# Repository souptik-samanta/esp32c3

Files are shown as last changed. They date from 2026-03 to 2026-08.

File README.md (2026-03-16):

# ESP32-C3 Custom Development Board

A compact, custom-designed ESP32-C3 development board with USB-C connectivity, onboard antenna, and a clean PCB layout.

---

## 3D Render



The board features a USB-C connector on the left side, two tactile switches (BOOT and EN), the ESP32-C3 QFN package at the center-right, a PCB trace antenna on the far right, and a 4-pin UART header (3V3, RXD, TXD, GND) along the bottom edge. All passives are 0402/0603 for a tight layout.
with onboard temp humidity barometer and pressure
---

## PCB Layout

### 3d Render

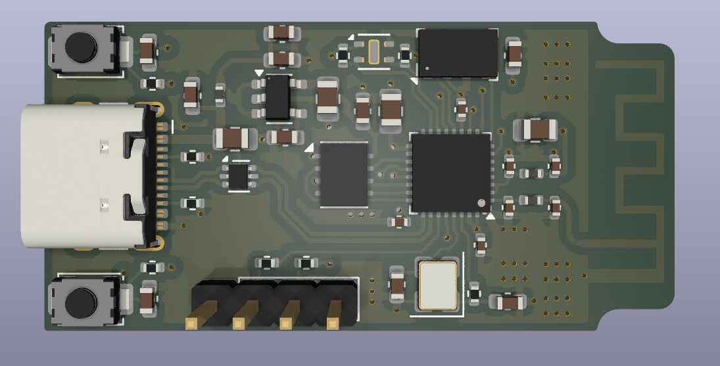
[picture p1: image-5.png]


### Front Copper

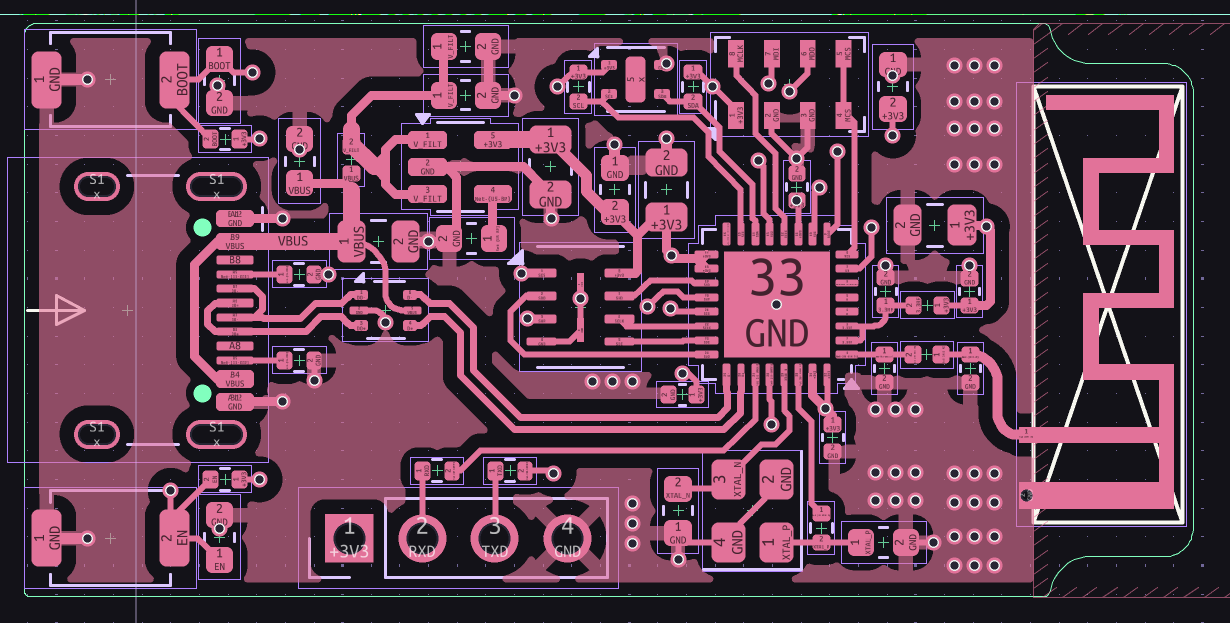
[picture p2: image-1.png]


### Back Copper

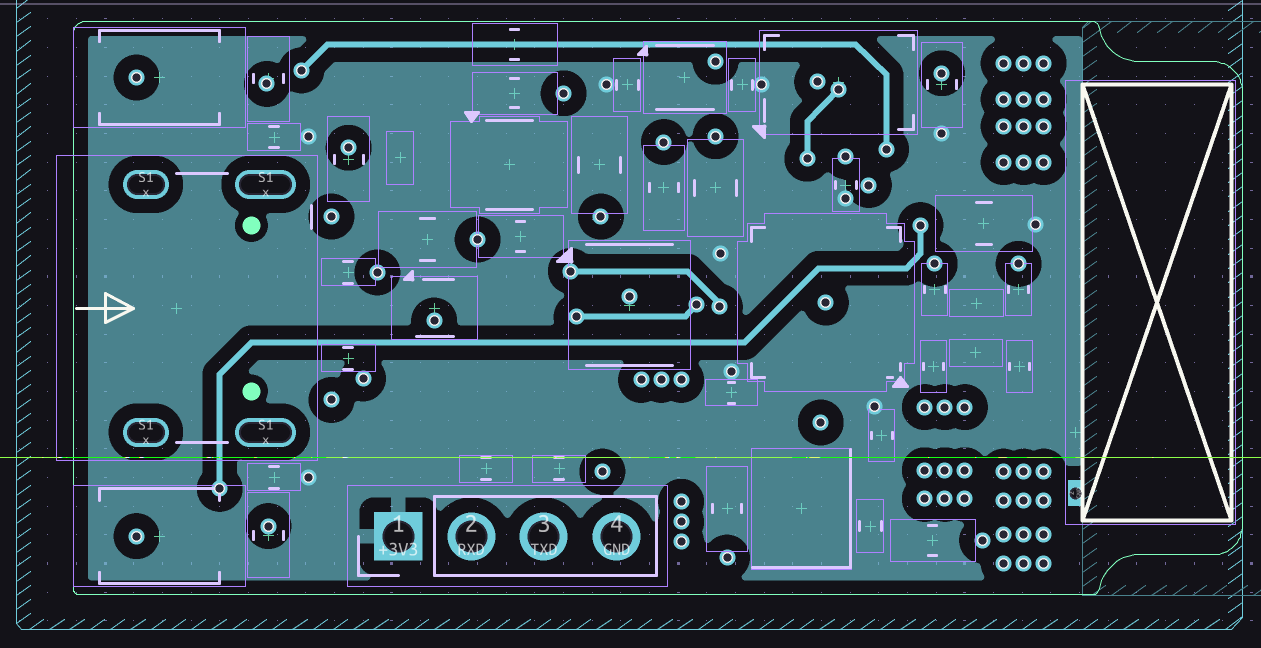
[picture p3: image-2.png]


### IN 1

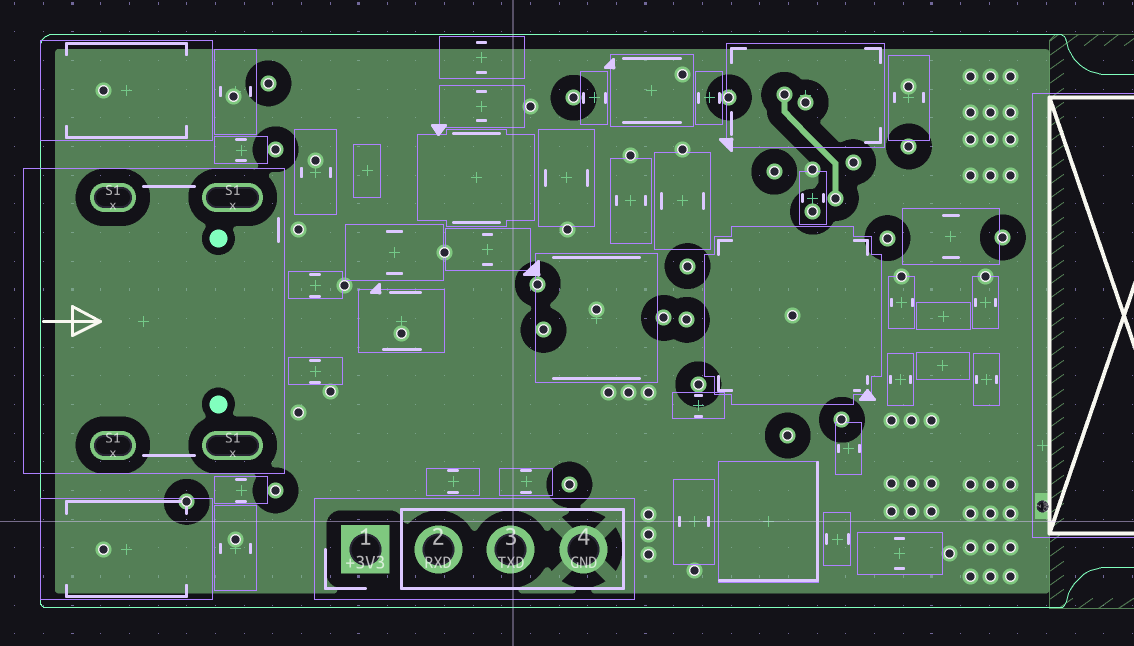
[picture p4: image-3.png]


### IN 2

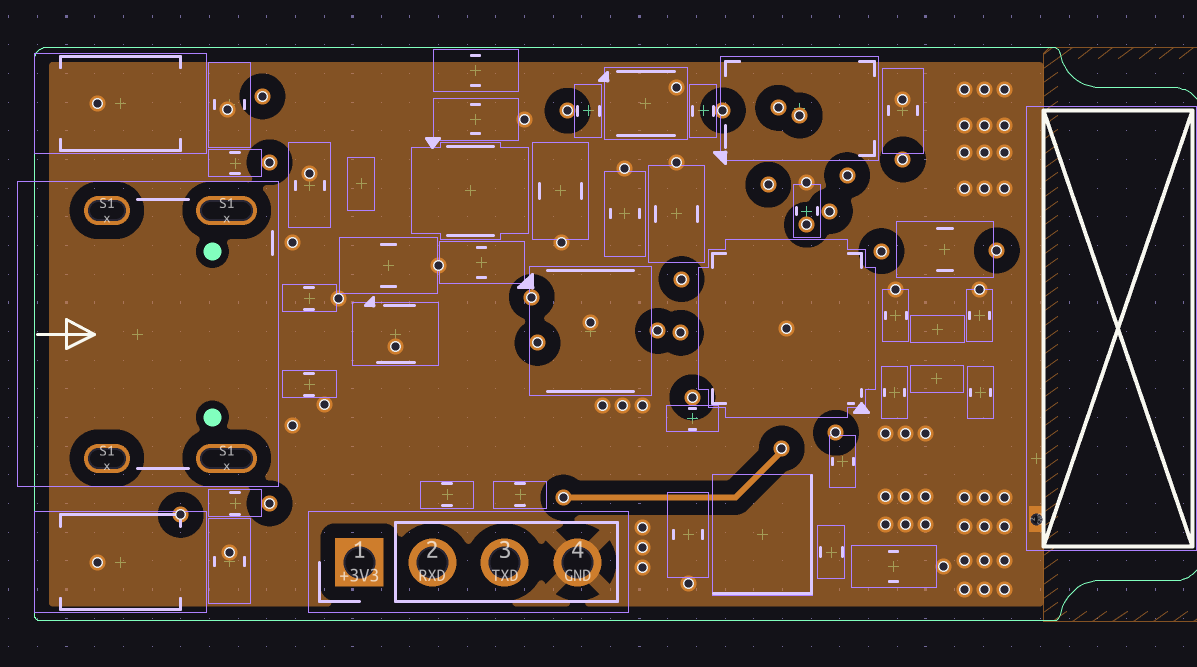
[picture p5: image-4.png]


### Board Outline

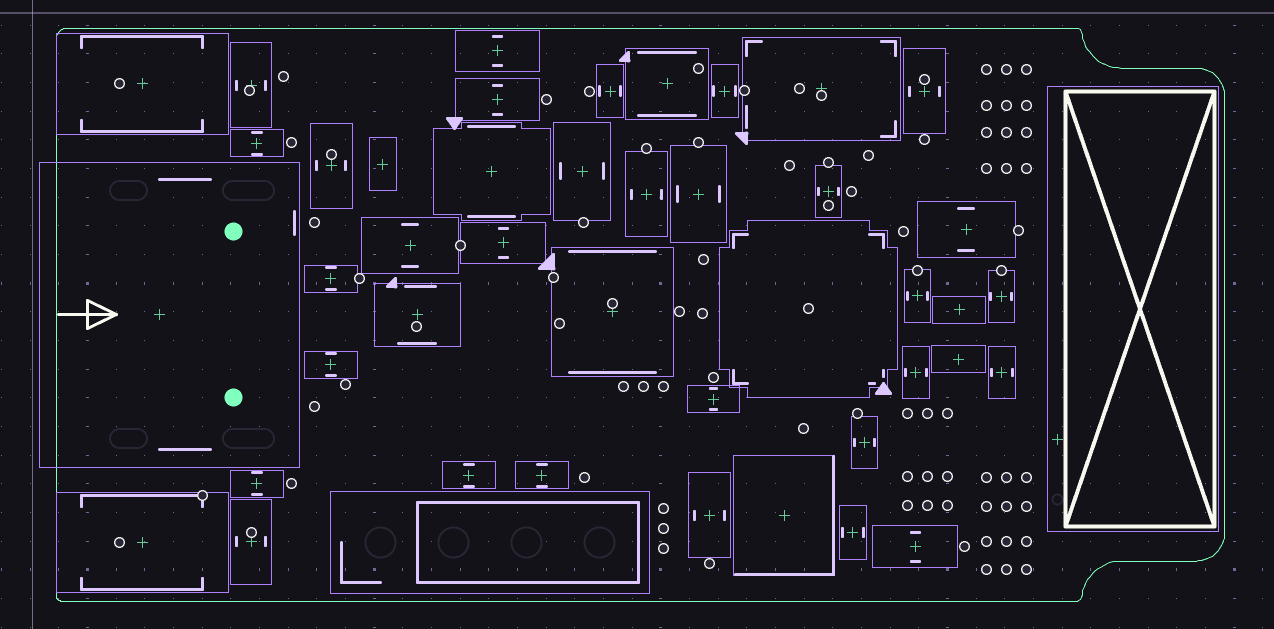
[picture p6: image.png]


---

## Features

- **Microcontroller:** ESP32-C3 (RISC-V single-core, up to 160 MHz)
- **Wireless:** 2.4 GHz Wi-Fi 4 and Bluetooth 5 (LE)
- **USB-C:** For power and programming, no external UART adapter needed
- **PCB Antenna:** Integrated trace antenna, no external module required
- **UART Header:** 4-pin breakout (3V3, RXD, TXD, GND) for serial debugging
- **Buttons:** BOOT and EN (reset) tactile switches
- **Power:** USB 5V input with onboard 3.3V regulation
- **Form Factor:** Compact two-layer board, hand-solderable with hot air

---

## Pin Header

| Pin | Function |
|-----|---|
| 1 | +3V3 |
| 2 | RXD |
| 3 | TXD |
| 4 | GND |

---

## Getting Started

1. Connect the board via USB-C to your computer.
2. Install the [ESP-IDF](https://docs.espressif.com/projects/esp-idf/en/latest/esp32c3/get-started/) toolchain or use the Arduino core for ESP32.
3. Hold the BOOT button while pressing EN to enter download mode.
4. Flash your firmware and hit EN to run.

For serial debugging without USB, wire up the 4-pin UART header to any USB-to-serial adapter at 3.3V logic levels.

## License

Hardware design files are provided as-is. Use at your own risk. Feel free to fork, modify, and build on this design for personal or commercial projects.

To make this 
Please download the esp32.zip(gerber files)
go to jlcpcb upload
upload the BOM AND cpl files and order!!
that simple

# Bill of Materials (BOM)

| Comment | Designator | Footprint | JLCPCB Part # |
|---|---|---|---|
| W25Q128JVP | U2 | Winbond_USON-8-2EP_3x4mm_P0.8mm_EP0.2x0.8mm | C2999380 |
| RESET | SW2, SW1 | SW_SPST_TS-1088-xR020 | C778164 |
| 27pF | C1, C2 | 0603 | C1656 |
| 470Ω | R3, R4 | 0402 | C25117 |
| USBLC6-2P6 | U3 | SOT-666 | C15999 |
| 10µF | C14, C15, C3, C7 | 0805 | C440198 |
| 100nF | C4, C5, C6, C8, C9 | 0402 | C1525 |
| 5.1KΩ | R2, R5, R6, R7, R8, R9 | 0402 | C25905 |
| ESP32-C3 | U1 | QFN-32-1EP_5x5mm_P0.5mm_EP3.7x3.7mm | C2838500 |
| 22Ω | R1 | 0402 | C25092 |
| 100nF | C10, C11, C12, C13, C16, C18, C19 | 0603 | C14663 |
| USB_C_Receptacle_USB2.0_14P | J1 | USB_C_Receptacle_HCTL_HC-TYPE-C-16P-01A | C2997432 |
| MS5611-01BA | U4 | LGA-8_3x5mm_P1.25mm | C15639 |
| 2.2µF | C17 | 0603 | C23630 |
| 2.2nH | L1, L2, L3 | 0402 | C6652831 |
| SPX3819M5-L-3-3 | U5 | SOT-23-5 | C20617301 |
| 3.3pF | C20, C21 | 0402 | C1565 |
| Crystal_GND24 | Y2 | Crystal_SMD_3225-4Pin_3.2x2.5mm | C5444549 |
| SHTC3 | U6 | Sensirion_DFN-4-1EP_2x2mm_P1mm_EP0.7x1.6mm | C2880044 |

---

## Cost Breakdown

- PCB Fabrication Cost: **$10 USD**
- Total Cost (Including Shipping): **$~ 162 USD**

# How to use it / assemble it
Go to jlcpcb upload gerber select pcba 
give the cpl and desgnator files
order it
wait 
and there u have it 
connect usb c cable use arduino ide thonny esp32 tool whatever u want lol
---

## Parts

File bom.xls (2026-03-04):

Comment | Designator | Footprint | JLCPCB Part #
W25Q128JVP | U2 | Winbond_USON-8-2EP_3x4mm_P0.8mm_EP0.2x0.8mm | C2999380
RESET | SW2,SW1,SW2,SW1 | SW_SPST_TS-1088-xR020 | C778164
27pF | C1,C2 | 0603 | C1656
470 | R3,R4 | 0402 | C25117
USBLC6-2P6 | U3 | SOT-666 | C15999
10u | C14,C15,C3,C7 | 0805 | C440198
100n | C4,C5,C6,C8,C9 | 0402 | C1525
5.1K | R2,R5,R6,R7,R8,R9 | 0402 | C25905
ESP32-C3 | U1 | QFN-32-1EP_5x5mm_P0.5mm_EP3.7x3.7mm | C2838500
22 | R1 | 0402 | C25092
100n | C10,C11,C12,C13,C16,C18,C19 | 0603 | C14663
USB_C_Receptacle_USB2.0_14P | J1 | USB_C_Receptacle_HCTL_HC-TYPE-C-16P-01A | C2997432
MS5611-01BA | U4 | LGA-8_3x5mm_P1.25mm | C15639
2.2u | C17 | 0603 | C23630
2.2nH | L1,L2,L3 | 0402 | C6652831
SPX3819M5-L-3-3 | U5 | SOT-23-5 | C20617301
3.3pF | C20,C21 | 0402 | C1565
Crystal_GND24 | Y2 | Crystal_SMD_3225-4Pin_3.2x2.5mm | C5444549
SHTC3 | U6 | Sensirion_DFN-4-1EP_2x2mm_P1mm_EP0.7x1.6mm | C2880044

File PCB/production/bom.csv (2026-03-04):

Designator | Footprint | Quantity | Value | LCSC Part #
AE1 | Texas_SWRA117D_2.4GHz_Left | 1 | Antenna_Shield
C1, C2 | 0603 | 2 | 27pF
C10, C11, C12, C13, C16, C18, C19 | 0603 | 7 | 100n
C14, C15, C3, C7 | 0805 | 4 | 10u
C17 | 0603 | 1 | 2.2u
C20, C21 | 0402 | 2 | 3.3pF
C4, C5, C6, C8, C9 | 0402 | 5 | 100n
J1 | USB_C_Receptacle_HCTL_HC-TYPE-C-16P-01A | 1 | USB_C_Receptacle_USB2.0_14P
J2 | PinHeader_1x04_P2.54mm_Vertical | 1 | Conn_01x04_Pin
L1, L2, L3 | 0402 | 3 | 2.2nH
R1 | 0402 | 1 | 22
R2, R5, R6, R7, R8, R9 | 0402 | 6 | 5.1K
R3, R4 | 0402 | 2 | 470
SW1 | SW_SPST_TS-1088-xR020 | 1 | RESET
SW2 | SW_SPST_TS-1088-xR020 | 1 | BOOT
U1 | QFN-32-1EP_5x5mm_P0.5mm_EP3.7x3.7mm | 1 | ESP32-C3
U2 | Winbond_USON-8-2EP_3x4mm_P0.8mm_EP0.2x0.8mm | 1 | W25Q128JVP
U3 | SOT-666 | 1 | USBLC6-2P6
U4 | LGA-8_3x5mm_P1.25mm | 1 | MS5611-01BA
U5 | SOT-23-5 | 1 | SPX3819M5-L-3-3
U6 | Sensirion_DFN-4-1EP_2x2mm_P1mm_EP0.7x1.6mm | 1 | SHTC3
Y2 | Crystal_SMD_3225-4Pin_3.2x2.5mm | 1 | Crystal_GND24

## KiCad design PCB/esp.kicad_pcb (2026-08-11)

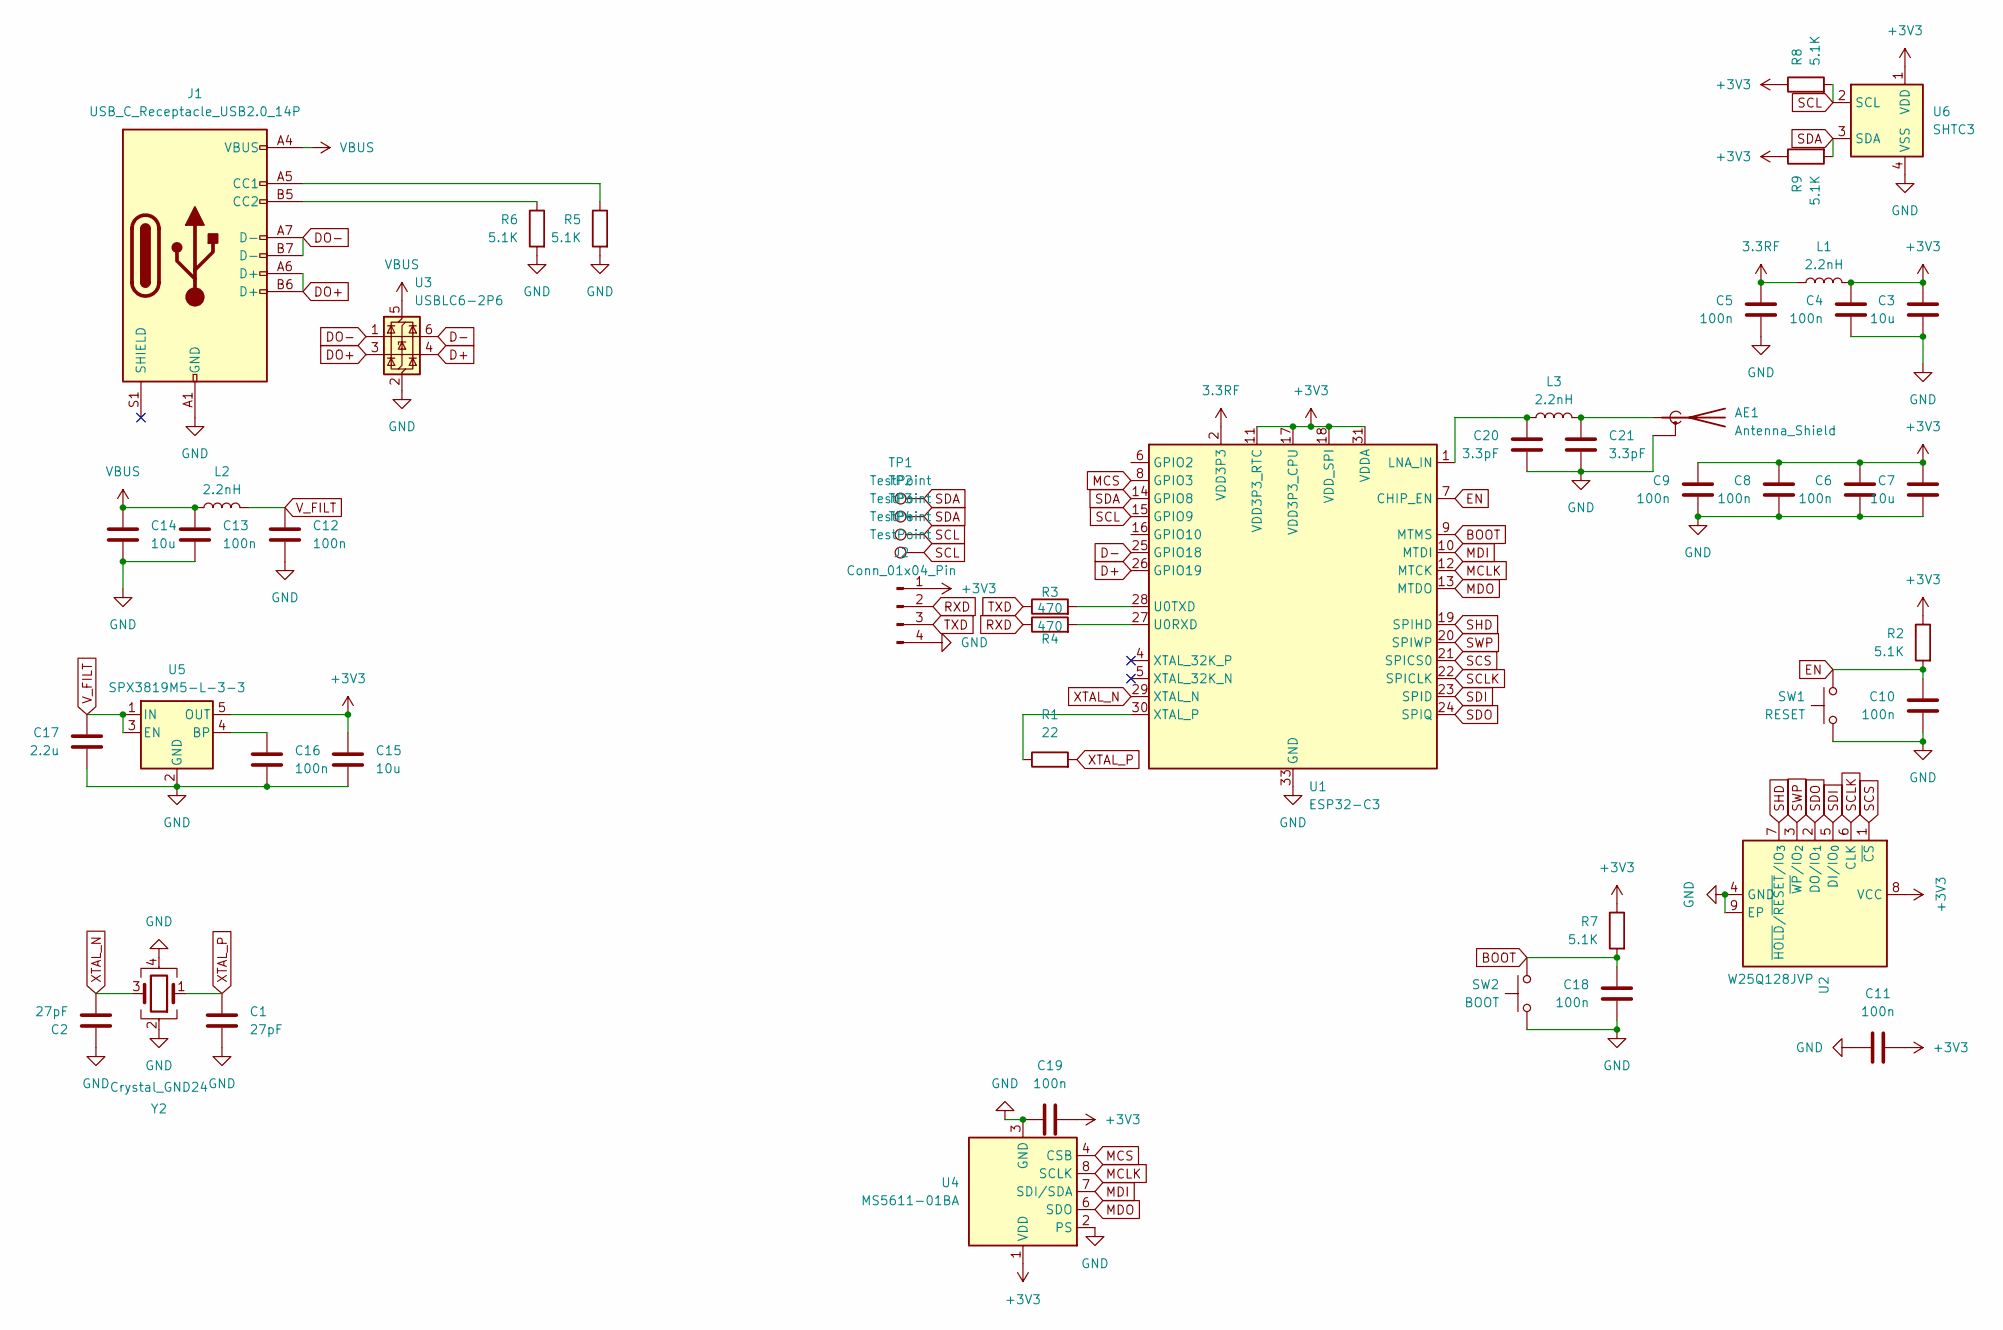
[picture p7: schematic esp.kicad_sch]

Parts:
AE1: Antenna_Shield; Texas_SWRA117D_2.4GHz_Left
C1, C2: 27pF; C_0603_1608Metric
C3, C7, C14, C15: 10u; C_0805_2012Metric
C4, C5, C6, C8, C9: 100n; C_0402_1005Metric
C10, C11, C12, C13, C16, C18, C19: 100n; C_0603_1608Metric
C17: 2.2u; C_0603_1608Metric
C20, C21: 3.3pF; C_0402_1005Metric
J1: USB_C_Receptacle_USB2.0_14P; USB_C_Receptacle_HCTL_HC-TYPE-C-16P-01A
J2: Conn_01x04_Pin; PinHeader_1x04_P2.54mm_Vertical
L1, L2, L3: 2.2nH; L_0402_1005Metric
R1: 22; R_0402_1005Metric
R2, R5, R6, R7, R8, R9: 5.1K; R_0402_1005Metric
R3, R4: 470; R_0402_1005Metric
SW1: RESET; SW_SPST_TS-1088-xR020
SW2: BOOT; SW_SPST_TS-1088-xR020
TP1, TP2, TP3, TP4: TestPoint; PinHeader_1x01_P1.00mm_Vertical
U1: ESP32-C3; QFN-32-1EP_5x5mm_P0.5mm_EP3.7x3.7mm
U2: W25Q128JVP; Winbond_USON-8-2EP_3x4mm_P0.8mm_EP0.2x0.8mm
U3: USBLC6-2P6; SOT-666
U4: MS5611-01BA; LGA-8_3x5mm_P1.25mm
U5: SPX3819M5-L-3-3; SOT-23-5
U6: SHTC3; Sensirion_DFN-4-1EP_2x2mm_P1mm_EP0.7x1.6mm
Y2: Crystal_GND24; Crystal_SMD_3225-4Pin_3.2x2.5mm

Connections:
3.3RF: C5.1, L1.2, U1.2 (VDD3P3), U1.3 (VDD3P3)
+3V3: C3.1, C4.1, C6.1, C7.1, C8.1, C9.1, C11.2, C15.1, C19.2, J2.1, L1.1, R2.1, R7.1, R8.1, R9.1, U1.11 (VDD3P3_RTC), U1.17 (VDD3P3_CPU), U1.18 (VDD_SPI), U1.31 (VDDA), U1.32 (VDDA), U2.8 (VCC), U4.1 (VDD), U5.5 (OUT), U6.1 (VDD)
BOOT: C18.1, R7.2, SW2.2, U1.9 (MTMS)
D+: U1.26 (GPIO19), U3.4 (I/O2)
D-: U1.25 (GPIO18), U3.6 (I/O1)
DO+: J1.A6 (D+), J1.B6 (D+), U3.3 (I/O2)
DO-: J1.A7 (D-), J1.B7 (D-), U3.1 (I/O1)
EN: C10.1, R2.2, SW1.2, U1.7 (CHIP_EN)
GND: AE1.2 (Shield), C1.2, C2.1, C3.2, C4.2, C5.2, C6.2, C7.2, C8.2, C9.2, C10.2, C11.1, C12.2, C13.2, C14.2, C15.2, C16.2, C17.2, C18.2, C19.1, C20.2, C21.2, J1.A1 (GND), J1.A12 (GND), J1.B1 (GND), J1.B12 (GND), J2.4, R5.2, R6.2, SW1.1, SW2.1, U1.33 (GND), U2.4 (GND), U2.9 (EP), U3.2 (GND), U4.2 (PS), U4.3 (GND), U5.2 (GND), U6.4 (VSS), Y2.2, Y2.4
MCLK: U1.12 (MTCK), U4.8 (SCLK)
MCS: U1.8 (GPIO3), U4.4 (CSB), U4.5 (CSB)
MDI: U1.10 (MTDI), U4.7 (SDI/SDA)
MDO: U1.13 (MTDO), U4.6 (SDO)
unnamed: AE1.1 (A), C21.1, L3.1
unnamed: J1.A5 (CC1), R5.1
unnamed: J1.B5 (CC2), R6.1
unnamed: C20.1, L3.2, U1.1 (LNA_IN)
unnamed: R4.2, U1.27 (U0RXD)
unnamed: R3.2, U1.28 (U0TXD)
unnamed: R1.1, U1.30 (XTAL_P)
unnamed: C16.1, U5.4 (BP)
RXD: J2.2, R4.1
SCL: R8.2, TP3.1, TP4.1, U1.15 (GPIO9), U6.2 (SCL)
SCLK: U1.22 (SPICLK), U2.6 (CLK)
SCS: U1.21 (SPICS0), U2.1 (~CS)
SDA: R9.2, TP1.1, TP2.1, U1.14 (GPIO8), U6.3 (SDA)
SDI: U1.23 (SPID), U2.5 (DI/IO_{0})
SDO: U1.24 (SPIQ), U2.2 (DO/IO_{1})
SHD: U1.19 (SPIHD), U2.7 (~HOLD/~RESET/IO_{3})
SWP: U1.20 (SPIWP), U2.3 (~WP/IO_{2})
TXD: J2.3, R3.1
VBUS: C13.1, C14.1, J1.A4 (VBUS), J1.A9 (VBUS), J1.B4 (VBUS), J1.B9 (VBUS), L2.1, U3.5 (VBUS)
V_FILT: C12.1, C17.1, L2.2, U5.1 (IN), U5.3 (EN)
XTAL_N: C2.2, U1.29 (XTAL_N), Y2.3
XTAL_P: C1.1, R1.2, Y2.1

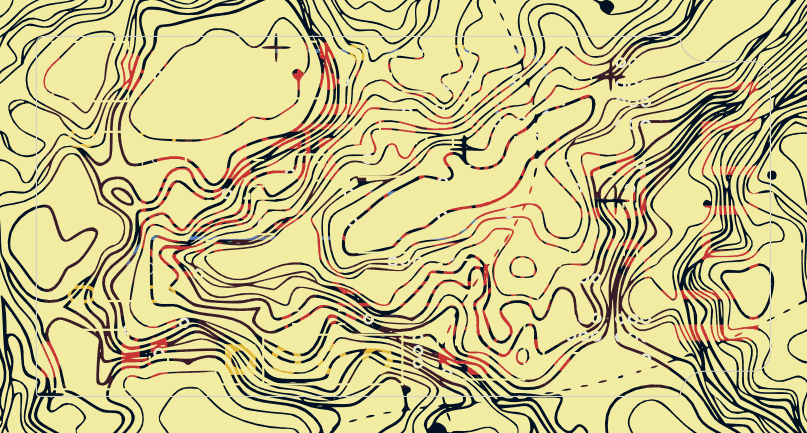
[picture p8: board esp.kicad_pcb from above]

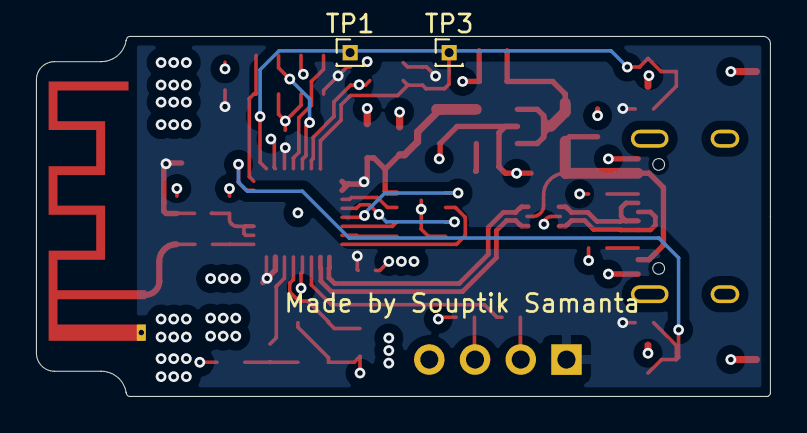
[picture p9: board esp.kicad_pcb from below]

Board: 4 copper layers, 40.8 x 20.0 mm, 48 parts (2 on the bottom side), 35 nets.

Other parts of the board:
.: LOGO

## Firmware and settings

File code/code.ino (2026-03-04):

#include <WiFi.h>
#include <WebServer.h>

// AP credentials
const char* ssid = "ESP32C3_AP";
const char* password = "12345678";

WebServer server(80);

void handleRoot() {
  server.send(200, "text/html", "<h1>Hello World</h1>");
}

void setup() {
  Serial.begin(115200);

  // Start Access Point
  WiFi.softAP(ssid, password);

  Serial.println("Access Point Started");
  Serial.print("IP Address: ");
  Serial.println(WiFi.softAPIP());

  // Route
  server.on("/", handleRoot);

  // Start server
  server.begin();
  Serial.println("Web server started");
}

void loop() {
  server.handleClient();
}

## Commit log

2026-03-04 pushing before redoing everything
    [esp.kicad_pcb, esp.kicad_sch]
2026-03-04 Add BOM and Cost Breakdown to README
    Added Bill of Materials (BOM) and Cost Breakdown sections to the README.
2026-03-16 Assembly plan added
    [esp.kicad_pcb]
